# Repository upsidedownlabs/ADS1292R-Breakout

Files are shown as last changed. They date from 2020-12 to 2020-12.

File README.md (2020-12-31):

# Upside Down Labs ADS1292R



Upside Down Lab's ADS1292R breakout board for 2ch ECG + 1ch Respiration.

## v0.2 Board

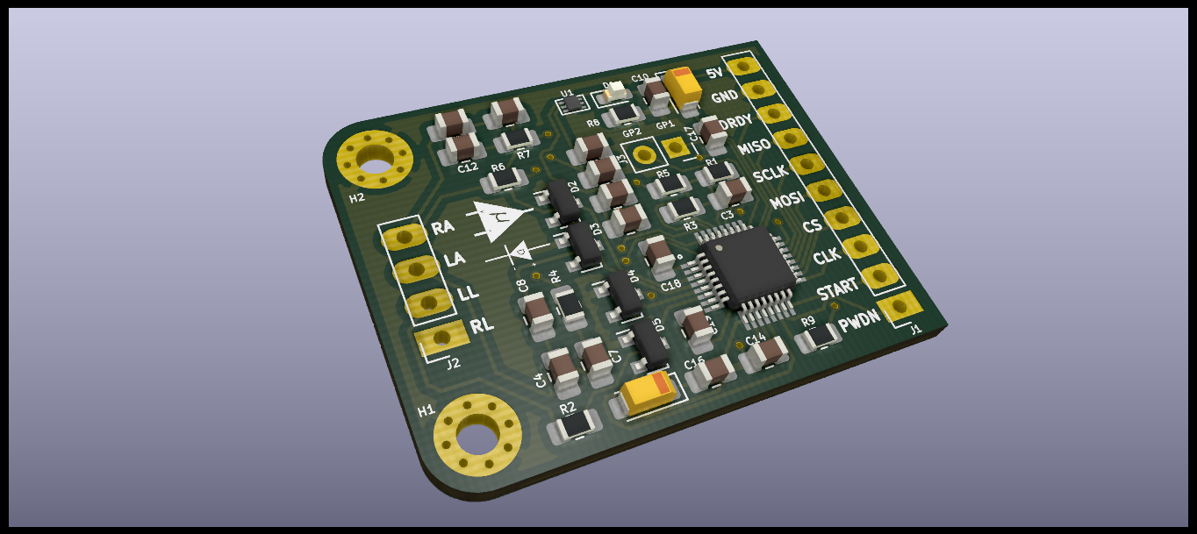
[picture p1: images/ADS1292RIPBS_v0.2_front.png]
Upside Down Labs ADS1292R v0.2 front


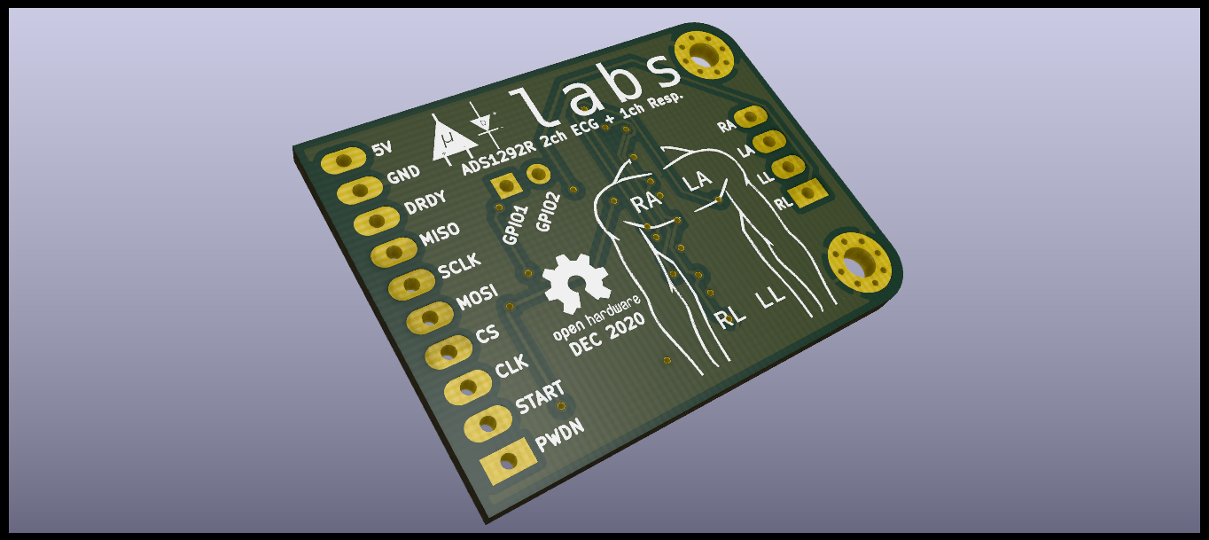
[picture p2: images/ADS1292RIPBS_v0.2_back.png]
Upside Down Labs ADS1292R v0.2 back


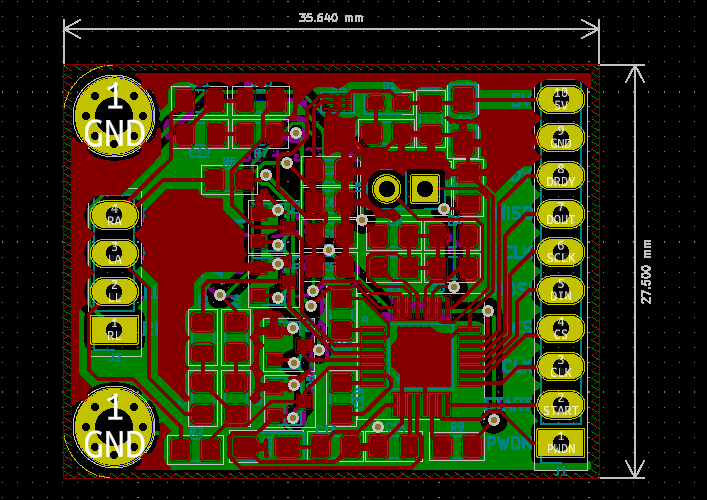
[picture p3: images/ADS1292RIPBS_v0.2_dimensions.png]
Upside Down Labs ADS1292R v0.2 dimensions


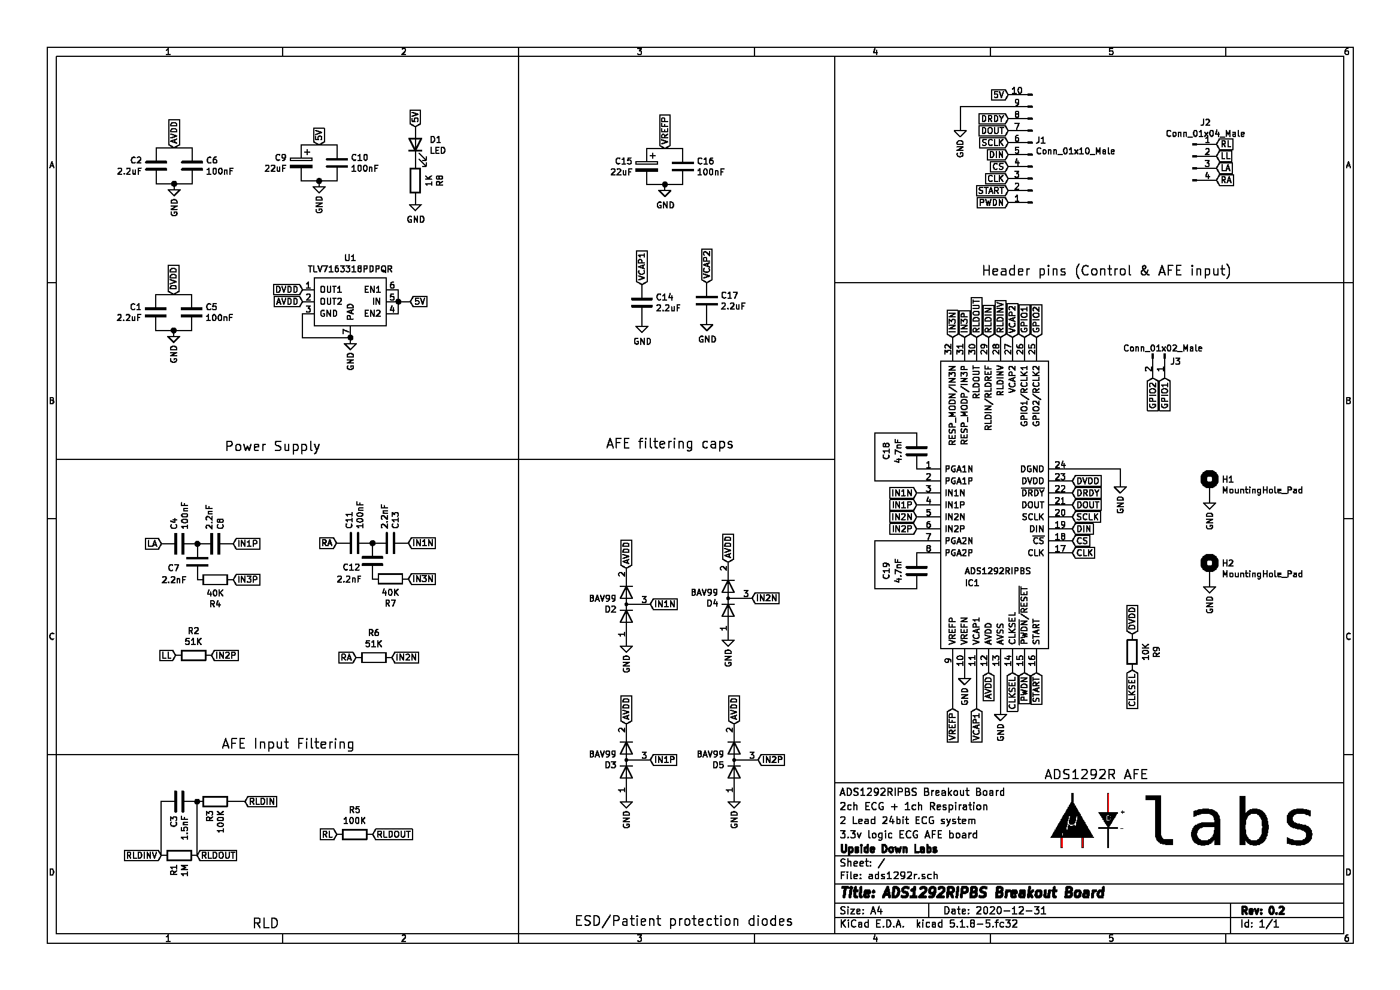
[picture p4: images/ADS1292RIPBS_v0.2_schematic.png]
Upside Down Labs ADS1292R v0.2 schematic


## License
#### Hardware
CERN Open Hardware License Version 2 - Strongly Reciprocal ([CERN-OHL-S-2.0](https://spdx.org/licenses/CERN-OHL-S-2.0.html)).

#### Software
MIT open source [license](http://opensource.org/licenses/MIT).

#### Documentation:
<br />This work is licensed under a <a rel="license" href="http://creativecommons.org/licenses/by/4.0/">Creative Commons Attribution 4.0 International License</a>.

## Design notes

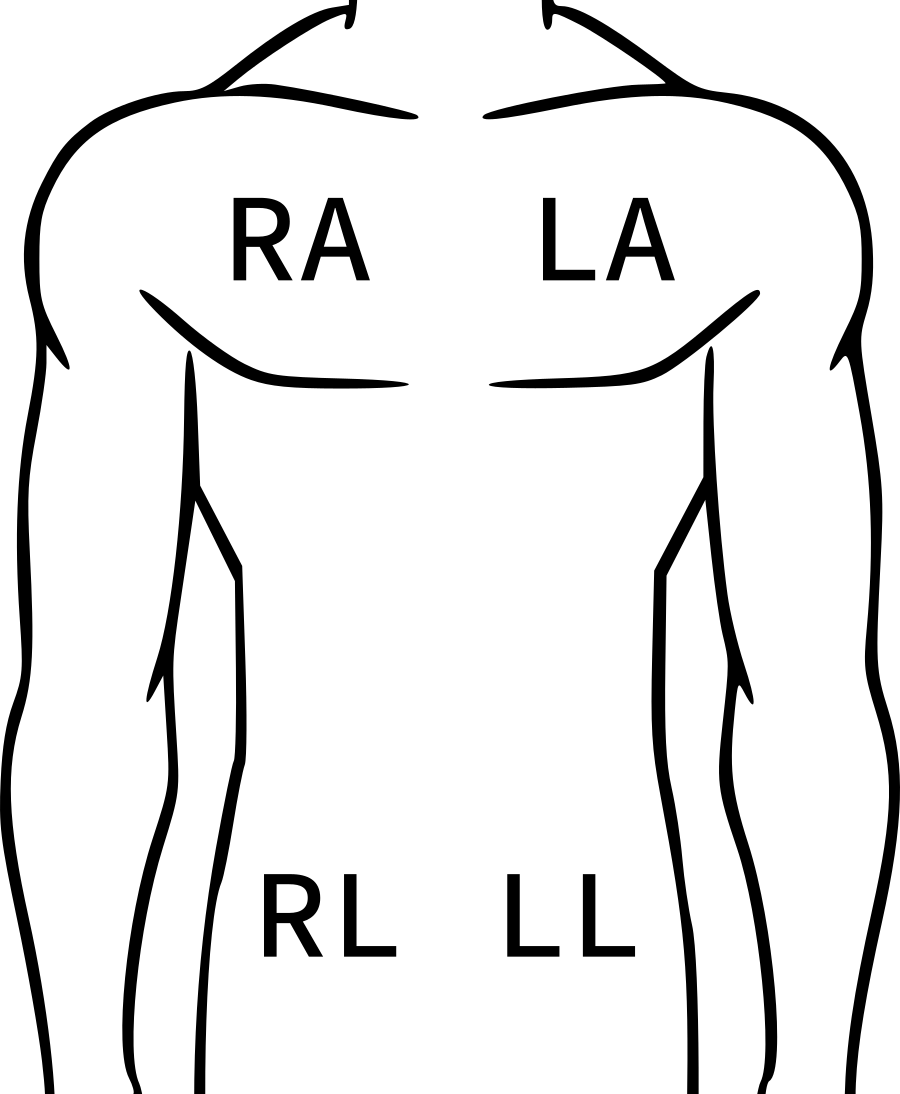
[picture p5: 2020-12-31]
images/torso.png

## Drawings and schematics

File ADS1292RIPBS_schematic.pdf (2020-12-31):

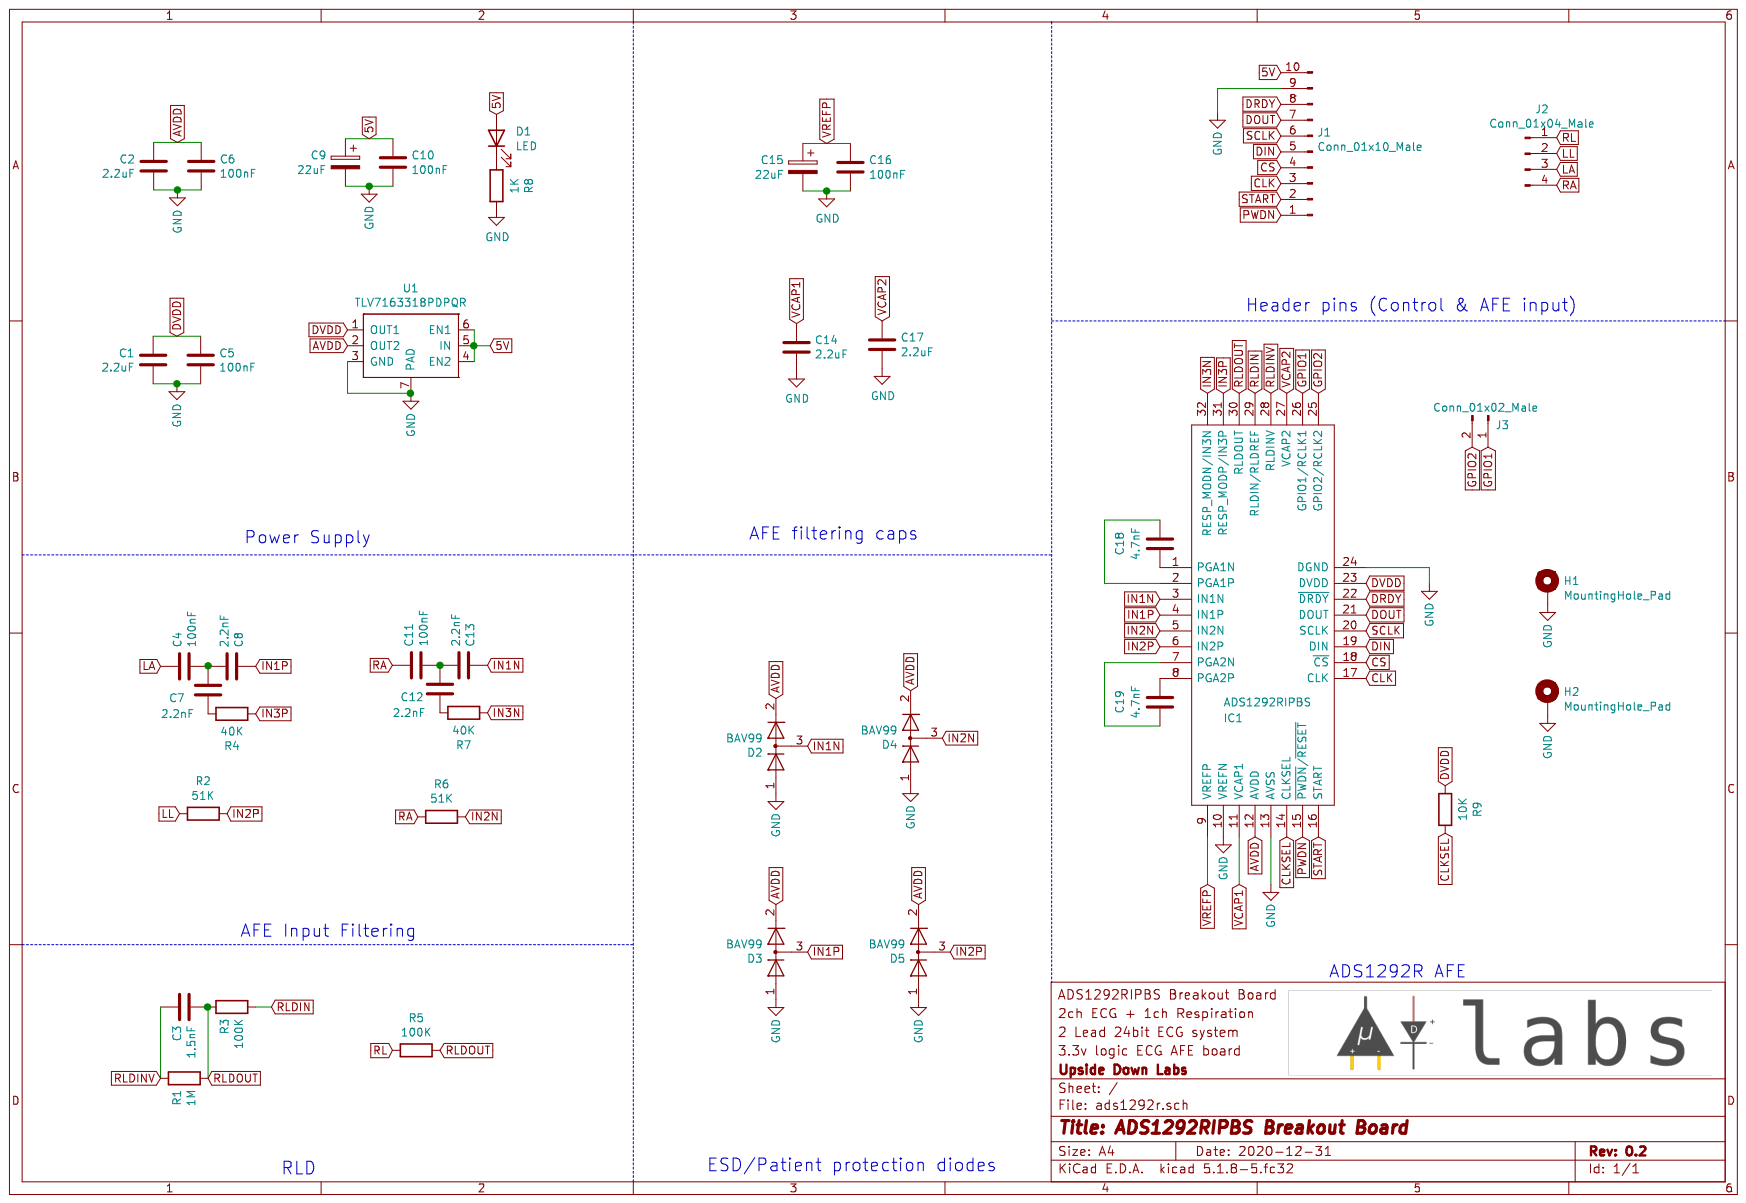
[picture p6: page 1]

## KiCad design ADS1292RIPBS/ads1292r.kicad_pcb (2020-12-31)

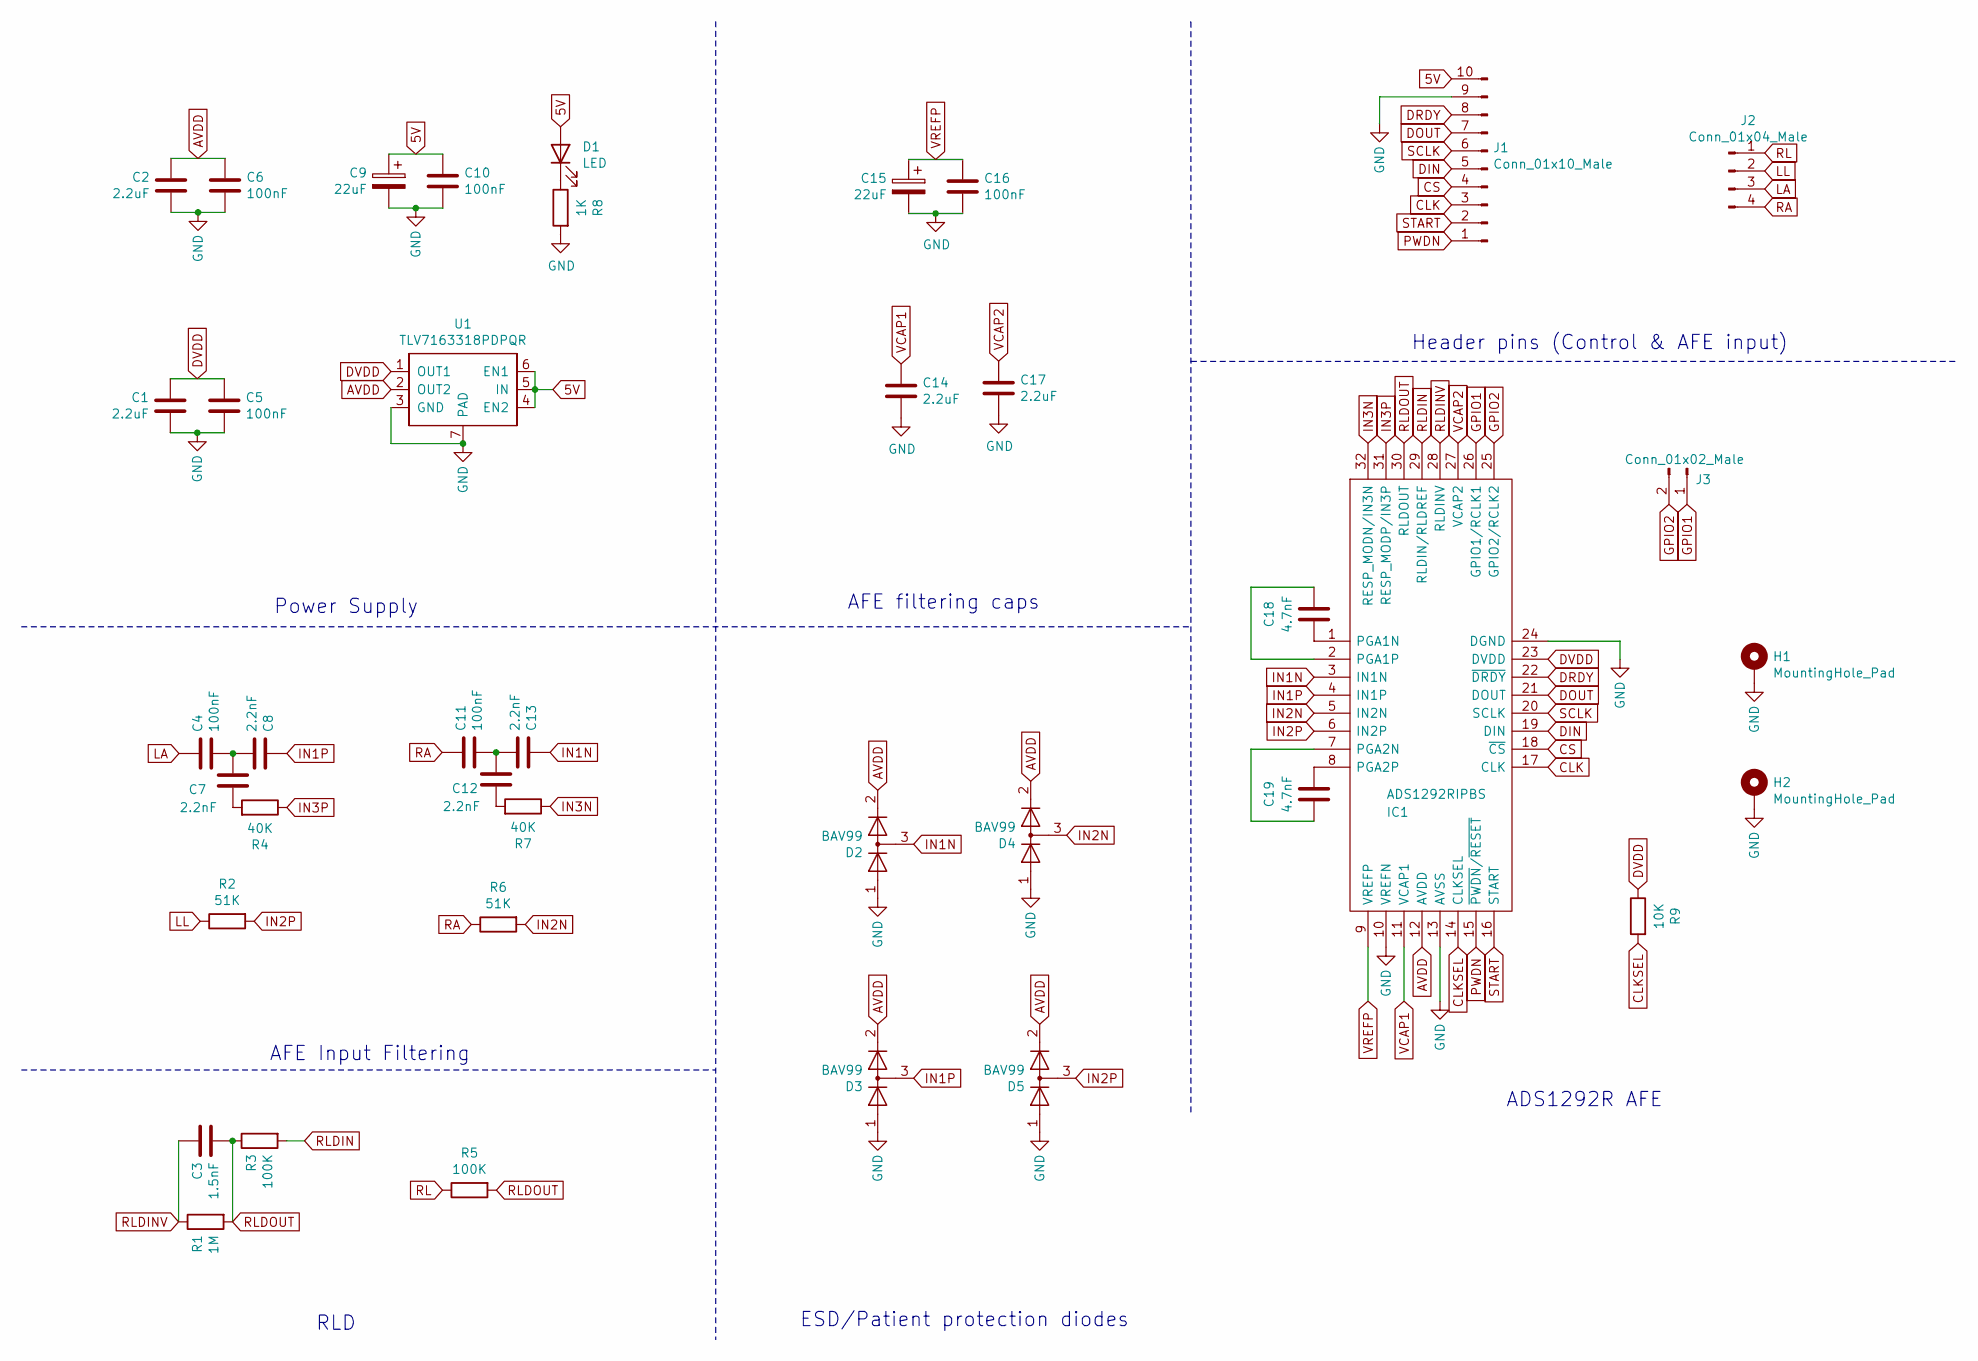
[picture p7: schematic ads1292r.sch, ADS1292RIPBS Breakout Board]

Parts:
C1, C2, C14, C17: 2.2uF; C_0805_2012Metric_Pad1.18x1.45mm_HandSolder
C3: 1.5nF; C_0805_2012Metric_Pad1.18x1.45mm_HandSolder
C4, C5, C6, C10, C11, C16: 100nF; C_0805_2012Metric_Pad1.18x1.45mm_HandSolder
C7, C8, C12, C13: 2.2nF; C_0805_2012Metric_Pad1.18x1.45mm_HandSolder
C9, C15: 22uF; CP_EIA-3216-18_Kemet-A_Pad1.58x1.35mm_HandSolder
C18, C19: 4.7nF; C_0805_2012Metric_Pad1.18x1.45mm_HandSolder
D1: LED; LED_0603_1608Metric_Pad1.05x0.95mm_HandSolder
D2, D3, D4, D5: BAV99; SOT-23
H1, H2: MountingHole_Pad; MountingHole_2.5mm_Pad_Via
IC1: ADS1292RIPBS; Manufacturer_Part_Number ADS1292RIPBS; Mouser Part Number 595-ADS1292RIPBS
J1: Conn_01x10_Male; PinSocket_1x10_P2.54mm_Vertical
J2: Conn_01x04_Male; PinSocket_1x04_P2.54mm_Vertical
J3: Conn_01x02_Male; PinSocket_1x02_P2.54mm_Vertical
R1: 1M; R_0805_2012Metric_Pad1.20x1.40mm_HandSolder
R2, R6: 51K; R_0805_2012Metric_Pad1.20x1.40mm_HandSolder
R3, R5: 100K; R_0805_2012Metric_Pad1.20x1.40mm_HandSolder
R4, R7: 40K; R_0805_2012Metric_Pad1.20x1.40mm_HandSolder
R8: 1K; R_0805_2012Metric_Pad1.20x1.40mm_HandSolder
R9: 10K; R_0805_2012Metric_Pad1.20x1.40mm_HandSolder
U1: TLV7163318PDPQR; S-PX2SON-N6

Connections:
5V: C9.1, C10.1, D1.2 (A), J1.10, U1.4 (EN2), U1.5 (IN), U1.6 (EN1)
AVDD: C2.1, C6.1, D2.2 (A), D3.2 (A), D4.2 (A), D5.2 (A), IC1.12 (AVDD), U1.2 (OUT2)
CLK: IC1.17 (CLK), J1.3
CLKSEL: IC1.14 (CLKSEL), R9.2
CS: IC1.18 (~CS), J1.4
DIN: IC1.19 (DIN), J1.5
DOUT: IC1.21 (DOUT), J1.7
DRDY: IC1.22 (~DRDY), J1.8
DVDD: C1.1, C5.1, IC1.23 (DVDD), R9.1, U1.1 (OUT1)
GND: C1.2, C2.2, C5.2, C6.2, C9.2, C10.2, C14.2, C15.2, C16.2, C17.2, D2.1 (K), D3.1 (K), D4.1 (K), D5.1 (K), H1.1, H2.1, IC1.10 (VREFN), IC1.13 (AVSS), IC1.24 (DGND), J1.9, R8.2, U1.3 (GND), U1.7 (PAD)
GPIO1: IC1.26 (GPIO1/RCLK1), J3.1
GPIO2: IC1.25 (GPIO2/RCLK2), J3.2
IN1N: C13.1, D2.3 (K), IC1.3 (IN1N)
IN1P: C8.1, D3.3 (K), IC1.4 (IN1P)
IN2N: D4.3 (K), IC1.5 (IN2N), R6.2
IN2P: D5.3 (K), IC1.6 (IN2P), R2.2
IN3N: IC1.32 (RESP_MODN/IN3N), R7.1
IN3P: IC1.31 (RESP_MODP/IN3P), R4.1
LA: C4.1, J2.3
LL: J2.2, R2.1
unnamed: C4.2, C7.1, C8.2
unnamed: C7.2, R4.2
unnamed: C11.2, C12.1, C13.2
unnamed: C12.2, R7.2
unnamed: C18.1, IC1.1 (PGA1N)
unnamed: C18.2, IC1.2 (PGA1P)
unnamed: C19.1, IC1.7 (PGA2N)
unnamed: C19.2, IC1.8 (PGA2P)
unnamed: D1.1 (K), R8.1
PWDN: IC1.15 (~PWDN~/~RESET), J1.1
RA: C11.1, J2.4, R6.1
RL: J2.1, R5.1
RLDIN: IC1.29 (RLDIN/RLDREF), R3.2
RLDINV: C3.1, IC1.28 (RLDINV), R1.1
RLDOUT: C3.2, IC1.30 (RLDOUT), R1.2, R3.1, R5.2
SCLK: IC1.20 (SCLK), J1.6
START: IC1.16 (START), J1.2
VCAP1: C14.1, IC1.11 (VCAP1)
VCAP2: C17.1, IC1.27 (VCAP2)
VREFP: C15.1, C16.1, IC1.9 (VREFP)

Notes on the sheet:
RLD
AFE Input Filtering
Power Supply
AFE filtering caps
ESD/Patient protection diodes
Header pins (Control & AFE input)
ADS1292R AFE

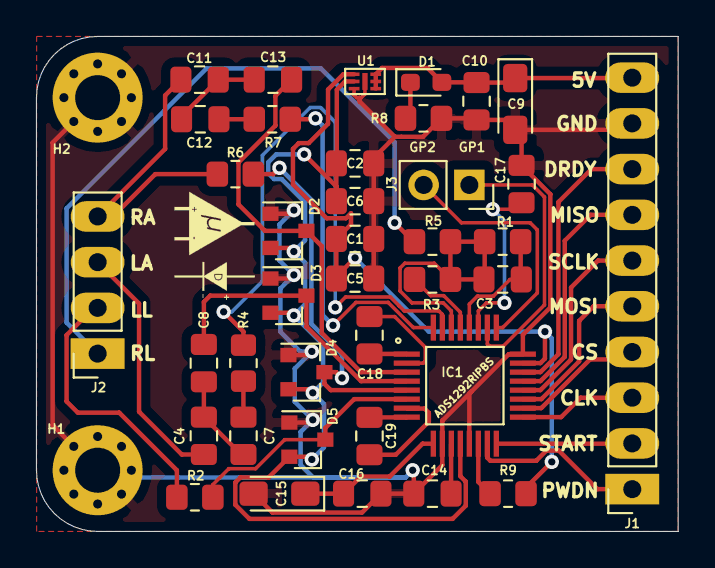
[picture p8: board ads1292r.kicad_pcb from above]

Board: 2 copper layers, 35.7 x 27.5 mm, 40 parts (0 on the bottom side), 40 nets.

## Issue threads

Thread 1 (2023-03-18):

Is there a problem with the power supply?

Drzad1024, 2023-03-18:
The OUT1 output pin of the TLV7163318PDPQR chip should be 3.3V, which is a DVDD. Then AVDD is 1.8V. According to the datasheet, shouldn't DVDD be 1.8V and AVDD be 3.3V? Is the painting reversed?

lorforlinux, 2025-01-14:
Hey @Drzad1024, AVDD can be up to 5.5V so connecting it to 3.3V is fine.

Closed 2025-01-14.

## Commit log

2020-12-30 ADS1292RIPBS v0.1
    [ads1292r.kicad_pcb, ads1292r.sch]
2020-12-31 add v0.2 schematic image
2020-12-31 update PCB
    [ads1292r.kicad_pcb]
